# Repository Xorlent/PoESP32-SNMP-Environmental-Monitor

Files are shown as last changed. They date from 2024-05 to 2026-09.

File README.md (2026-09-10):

# The $32 SNMP Environmental Monitor
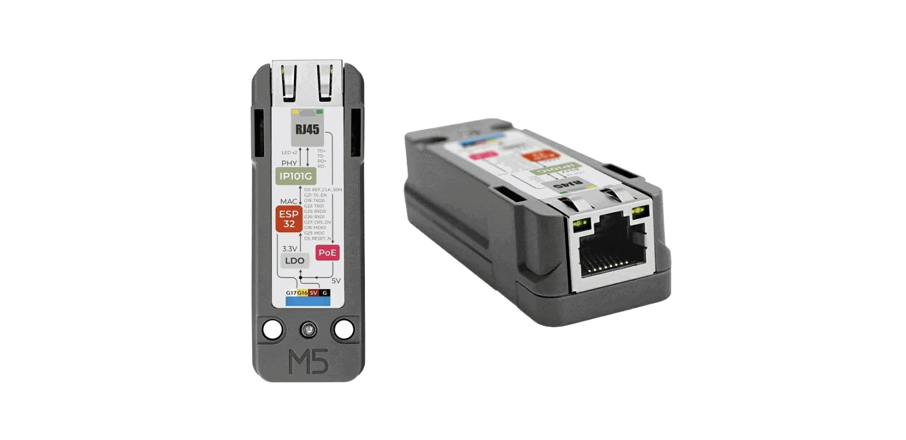
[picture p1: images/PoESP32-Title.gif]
PoESP32 Animated Image

## Background
With Vertiv unceremoniously stop-shipping and then discontinuing the [Geist Watchdog 15](https://www.vertiv.com/en-us/products-catalog/monitoring-control-and-management/monitoring/watchdog-15/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) during our deployment, we had to scramble to find a suitable equivalent device.  We were shocked to find a lack of decent options for small form-factor, PoE-powered devices that were not astronomically priced.  With M5Stack's PoE-powered ESP32 device in hand, we developed a network SNMP environmental monitor with a total all-in cost of less than 20% of competing products.

## Requirements
1. M5Stack [PoESP32 device](https://shop.m5stack.com/products/esp32-ethernet-unit-with-poe), or a newer [Unit-PoE-P4](https://shop.m5stack.com/products/unit-poe-with-esp32-p4), both around $25 USD
   - Notes on the Unit-PoE-P4:
     - Using the Unit-PoE-P4 significantly reduces the device operating specification from -17.7°C to 0°C and 60°C to 40°C
     - Requires NO disassembly or downloader kit, just a USB C cable for programming
     - The Unit-PoE-P4 device will not mount to any of the provided 3D-printable models.  I may produce revised designs for this if there is interest.
2. Sensor
   - M5Stack [ENV III sensor unit](https://shop.m5stack.com/products/env-iii-unit-with-temperature-humidity-air-pressure-sensor-sht30-qmp6988), currently $5.95 USD
   - or a custom SHT41-based sensor.  All files and instructions can be found in the /SHT4X folder.  As little as $2.20/each shipped in quantities of 30.
3. A single [M5Stack ESP32 Downloader kit](https://shop.m5stack.com/products/esp32-downloader-kit) (not required for Unit-PoE-P4), currently $9.95 USD

## Cost Analysis
One-time cost for a USB-to-serial device (PoESP32 only): $9.95 plus tax and shipping  
Total cost per unit: $31.85 plus tax and shipping  
Programming time per unit: < 10 minutes  

## Device Cost Comparison (temperature/humidity only)
- $32: this PoESP32-based device
- $220 before stop-ship: Vertiv Watchdog 15P (discontinued)
- $190 on sale: AKCP sensorProbe1+ Pro
- $315: NTI E-MICRO-TRHP
- $199: MONNIT PoE-X Temperature
- $295: Room Alert 3S

## Device Capability Comparison
This project produces a SNMPv1/2c temperature and humidity monitoring device with flashed configuration settings and no remote management capability.  Some would see this as a positive from a security-perspective, but it could prove challenging in network environments where change is constant.  A re-flash/re-programming is required to modify any configuration options:
- Host name
- Device IP and subnet
- IP gateway
- SNMP read community string
- Authorized SNMP monitoring node IP address list

__Bottom line: If you need SNMPv3 or desire web management and/or SNMP write functionality, you could enhance this project's code or simply purchase a commercial product.__  
_Update: See the [DHCP-Support Branch](https://github.com/Xorlent/PoESP32-SNMP-Environmental-Monitor/tree/DHCP-Support) to test the V.2.0 candidate with full DHCP configuration capabilities_

## Programming
_Once you've successfully programmed a single unit, skip step 1.  Repeating this process takes less than 5 minutes from start to finish._
1. [Set up your Arduino programming environment](https://github.com/Xorlent/PoESP32-SNMP-Environmental-Monitor/blob/main/ARDUINO-SETUP.md)
2. Disassemble the PoESP32 case (skip if using Unit-PoE-P4)
   - You will need a 1.5mm (M2) allen wrench to remove a single screw [pic](https://github.com/Xorlent/PoESP32-SNMP-Environmental-Monitor/blob/main/images/1-Allen.jpg)
   - Inserting a small flat head screwdriver into the slots flanking the Ethernet jack [pic](https://github.com/Xorlent/PoESP32-SNMP-Environmental-Monitor/blob/main/images/2-Slots.jpg), carefully separate the case halves; work it side by side to avoid damage [pic](https://github.com/Xorlent/PoESP32-SNMP-Environmental-Monitor/blob/main/images/3-Tabs.jpg)
> [!TIP]
> If you have fingernails, it can be quicker to slide a nail between the case halves, starting with the end opposite the Ethernet port and using another nail to pull the retaining tabs back
3. In Arduino, open the project file (PoESP32-SNMP-Environmental-Monitor.ino)
   - Edit the hostname, IP address, subnet, gateway, SNMP read community, and authorized hosts lists at the very top of the file.
   - Select Tools->Board->esp32 and select "ESP32 Dev Module" if using PoESP32
   - OR select Tools->Board->esp32 and select "ESP32P4 Dev Module" if using Unit-PoE-P4
     - Set ESP32P4 board parameters according to [this screenshot](https://github.com/Xorlent/PoESP32-SNMP-Environmental-Monitor/blob/main/images/ESP32P4-Config.jpg)
4. With the USB-to-serial adapter unplugged, insert the pins in the correct orientation on the back of the PoESP32 mainboard [pic](https://github.com/Xorlent/PoESP32-SNMP-Environmental-Monitor/blob/main/images/4-Programmer.jpg) (skip if using Unit-PoE-P4)
> [!WARNING]
> Do not plug the device into a powered Ethernet port until after step 7 or you risk damaging your USB port!
5. With light tension applied to ensure good connectivity to the programming through-hole vias on the PoESP32 (see step 4 pic), plug in the USB-to-serial adapter
   - The device is now in bootloader mode
   - For the Unit-PoE-P4, simply plug the USB cable into the USB port above the Ethernet jack
6. In Arduino
   - Select Tools->Port and select the USB-to-serial interface
     - If you're unsure, unplug the USB cable, look at the port list, then plug it back in and select the new entry (repeating step 5)
   - Select Sketch->Upload to flash the device
   - When you see something similar to the following, proceed to step 7.  If you see an error, try lowering the upload speed in the Tools menu.
     ```
     Writing at 0x000d0502... (100 %)
     Wrote 790896 bytes (509986 compressed) at 0x00010000 in 8.9 seconds (effective 714.8 kbit/s)...
     Hash of data verified.

     Leaving...
     Hard resetting via RTS pin...
7. Disconnect the USB cable and reassemble the case if applicable
8. Plug in the sensor accessory [pic](https://github.com/Xorlent/PoESP32-SNMP-Environmental-Monitor/blob/main/images/5-Assembled.jpg)
9. Connect the device to a PoE network port and mount as appropriate
   - The holes in the PoESP32 and ENV IV sensor cases work great with zip ties for rack install or screws if attaching to a backboard
     - See the /3Dmodels folder for print-able mounting plates or [Guidance and Limitations](https://github.com/Xorlent/PoESP32-SNMP-Environmental-Monitor/blob/main/README.md#guidance-and-limitations) for more detail
   - Do not mount the ENV IV directly on top of the PoESP32, as it generates enough heat to affect sensor readings
10. Configure your monitoring platform as appropriate
    - A list of valid OIDs this sensor will respond to can be found [here](https://github.com/Xorlent/PoESP32-SNMP-Environmental-Monitor/blob/main/OIDINFO.md)
    - Paessler (PRTG) produce a great freely-downloadable SNMP tester for Windows, available [here](https://www.paessler.com/tools/snmptester)
    - If you have PRTG, pre-configured device templates are available for this project at https://github.com/Xorlent/PRTG-OIDLIBS
    - Don't have a monitoring platform?  [PRTG Freeware](https://www.paessler.com/free_network_monitor) would support monitoring and alerting for up to 20 of these devices

## Guidance and Limitations
- For monitoring, configure one OID per sensor.  This custom SNMP parser will only respond to one OID per request.
- If you receive a "General Failure" when requesting a valid measurement OID, this means the device is having trouble communicating with the temperature/humidity sensor.
- If you request an invalid OID, expect no response.  The device will not process packets for requests that are not authorized or not a match for a valid OID.
- For high humidity environments, this device will activate an internal sensor heater under certain conditions to ensure more accurate readings.
- The device will respond to pings from any IP address within the routable network.
- Don't have PoE ports on your network switch?  No problem: https://www.amazon.com/gp/product/B0C239DGJF
- Need a simple solution for mounting the PoESP32 and environmental monitor as a unitized assembly?  Within the /3Dmodels folder you will find:
  1. PoESP32-Environmental-1RU-Base.step : 3D print model to mount the PoESP32 assembly into a 1U rack space (w/optional wire cover and LED lightguides)
  2. PoESP32-Environmental-Mini.step : 3D print model for zip tie mounting (space constrained)
  3. PoESP32-Environmental-Mini-Magnet.step : 3D print model for magnet mounting (space constrained, compatible with 8mm x 2mm disc magnets)
  4. PoESP32-Environmental-Mid.step : 3D print model for zip tie mounting
  5. PoESP32-Environmental-Mid-Magnet.step : 3D print model for magnet mounting (compatible with 8mm x 2mm disc magnets)
  6. If you want to modify the models and make your own custom design:
     - [Onshape link - 1RU Base](https://cad.onshape.com/documents/126ed9d0ea20223ee2558e2e/w/5dc774b929e3cc882e2ccc02/e/70eb0dc678e6fe37b06c7b4d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)
     - [Onshape link - 1RU Lightguides for single-material printing](https://cad.onshape.com/documents/126ed9d0ea20223ee2558e2e/w/5dc774b929e3cc882e2ccc02/e/16542899019e9250b0249f1e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)
     - [Onshape link - 1RU Wire Cover](https://cad.onshape.com/documents/126ed9d0ea20223ee2558e2e/w/5dc774b929e3cc882e2ccc02/e/cc43e711478951692c63e341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)
     - [Onshape link - Mini](https://cad.onshape.com/documents/126ed9d0ea20223ee2558e2e/w/f747afb8fc8c6e8e288e0fc9/e/70eb0dc678e6fe37b06c7b4d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)
     - [Onshape link - Mini Magnetic](https://cad.onshape.com/documents/126ed9d0ea20223ee2558e2e/w/bfca9ecb4e85ab436c8e3736/e/70eb0dc678e6fe37b06c7b4d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)
     - [Onshape link - Mid](https://cad.onshape.com/documents/126ed9d0ea20223ee2558e2e/w/86908f6e4038f162632614a8/e/70eb0dc678e6fe37b06c7b4d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)
     - [Onshape link - Mid Magnetic](https://cad.onshape.com/documents/126ed9d0ea20223ee2558e2e/w/887531df77e994a6e9e16eac/e/70eb0dc678e6fe37b06c7b4d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)

## Technical Information
- Operating Specifications
  - Operating temperature: 0°F (-17.7°C) to 140°F (60°C)
  - Operating humidity: 5% to 90% (RH), non-condensing
- Sensor Accuracy
  - ±0.2 °C，±1.8 %RH
- Power Consumption
  - 6W maximum via 802.3af Power-over-Ethernet
- Ethernet
  - IP101G PHY
  - 10/100 Mbit twisted pair copper
  - IEEE 802.3af Power-over-Ethernet
- I/O Configuration
  - SHT40 (ENV IV) or SHT30 (ENV III) temperature and humidity sensor
  - See [PORTINFO.md](https://github.com/Xorlent/PoESP32-SNMP-Environmental-Monitor/blob/main/PORTINFO.md)

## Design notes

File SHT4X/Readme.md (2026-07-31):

## This folder contains a temperature and humidity sensor that can be used in place of the now end-of-life M5Stack ENV-IV
1. A full PCB design that can be produced by JLCPCB for as little as $2.20 each (shipped) in quantities of 30
   - Upload the SHT41A.zip file to JLCPCB accepting all defaults
   - Select economic assembly service, top side only
   - Click "Next"
   - Upload SHT41A-BOM.csv for the "Bill of Materials" list
   - Upload SHT41A-all-pos.csv for the Pick & Place file
   - Click "Process BOM & CPL"
   - Ensure components match the BOM file (you can open this file in a text editor to verify results)  
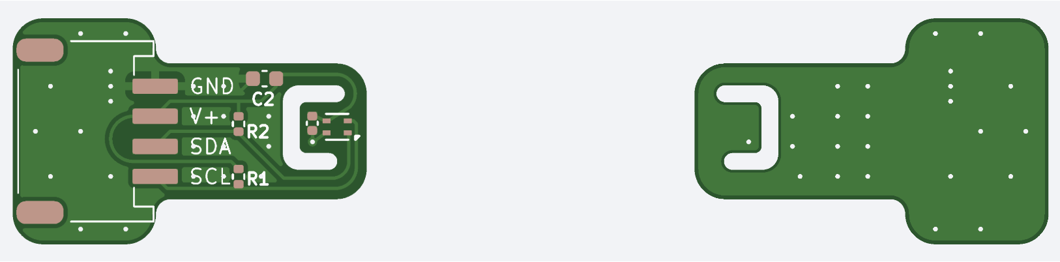
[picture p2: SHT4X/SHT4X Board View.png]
SHT4X Board View

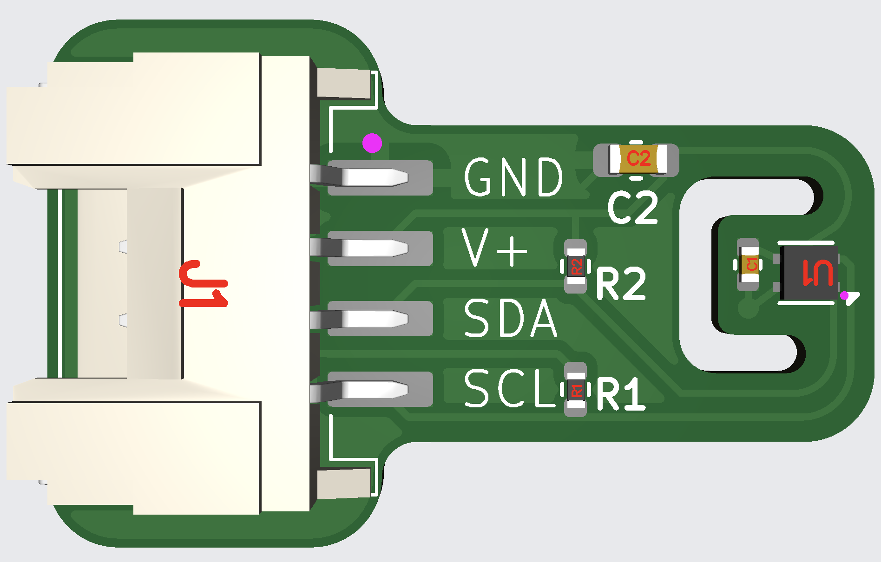
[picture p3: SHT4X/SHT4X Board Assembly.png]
SHT4X Board Assembly


2. A 3D-printable M5Stack sensor module compatible case
   - Print in PETG using a .4mm nozzle, .25mm layer height, .45mm extrusion width, 15% gyroid infill
   - Insert the assembled PC Board into the Bottom Shell
   - Using Weld-On #4 Cement, apply a small amount to the Top Shell barrels and the slots next to the connector opening
   - Assemble the shell halves, holding the top and bottom shells together for a few minutes

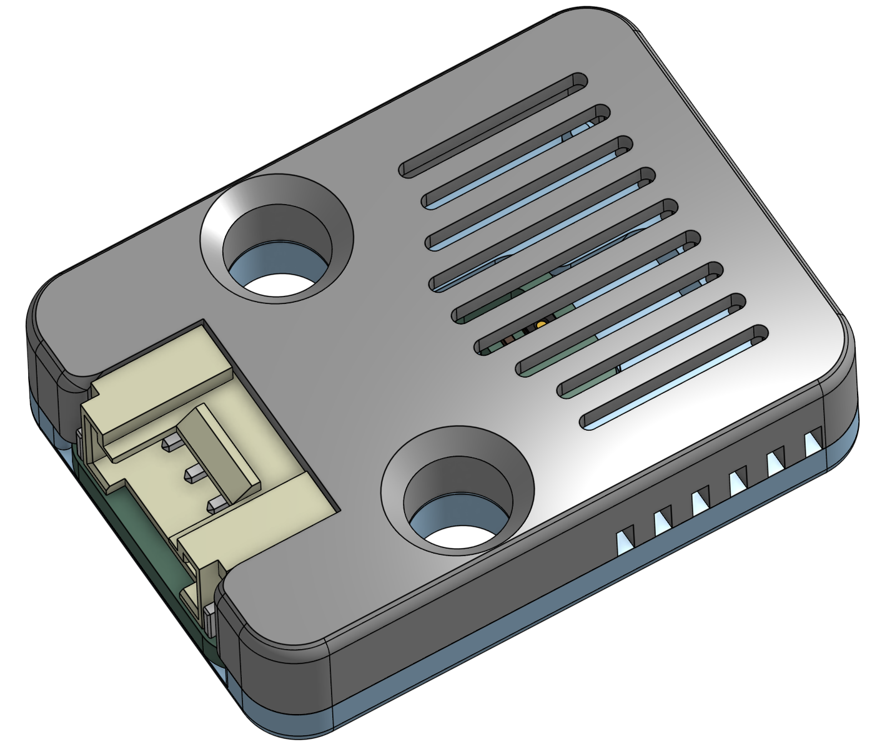
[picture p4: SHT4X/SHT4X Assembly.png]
SHT4X Sensor Module


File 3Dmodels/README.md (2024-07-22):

## This folder contains 3D print models for various device mounting options.
> [!NOTE]
> Take care to print these models in an appropriate material for the installation conditions (e.g. expected temperature and humidity)  
> For indoor, conditioned spaces, PETG is a great choice.  For high temperature environments, polycarbonate (PC) is recommended.
### PoESP32-SNMP-Environmental-1RU-Base, PoESP32-SNMP-Environmental-1RU-Lightguides, and PoESP32-Environmental-1RU-Base-Toolless
  - LED Lightguide features can be printed clear to allow Ethernet indicators to be seen even when mounted facing the rear of a rack
  - 1RU-Toolless-Nut and 1RU-Toolless-Stud only work with the PoESP32-Environmental-1RU-Base-Toolless model
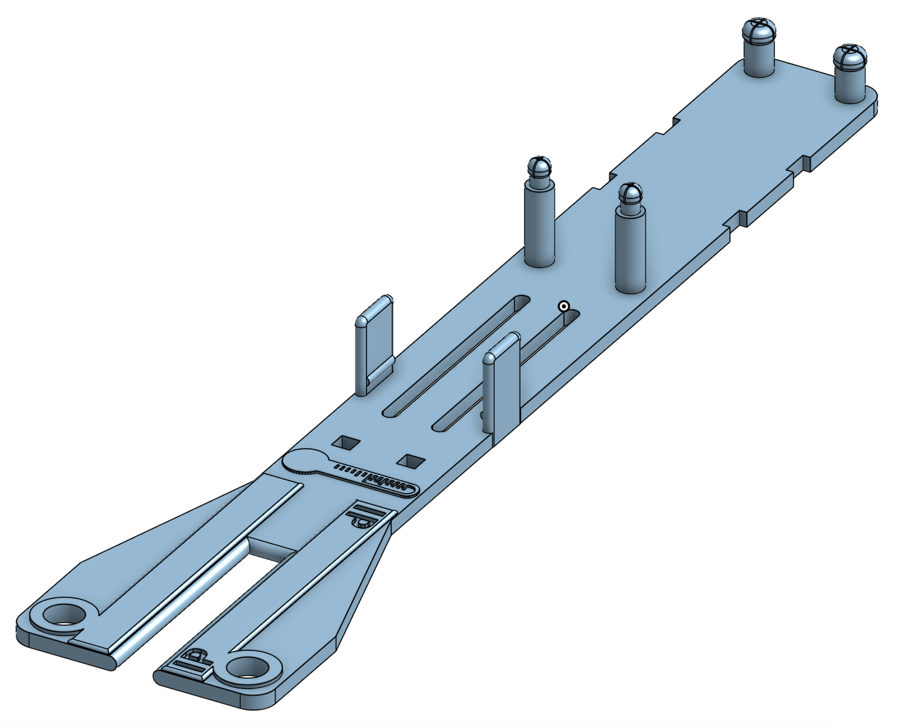
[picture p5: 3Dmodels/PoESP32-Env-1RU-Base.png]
PoESP32 1RU Model

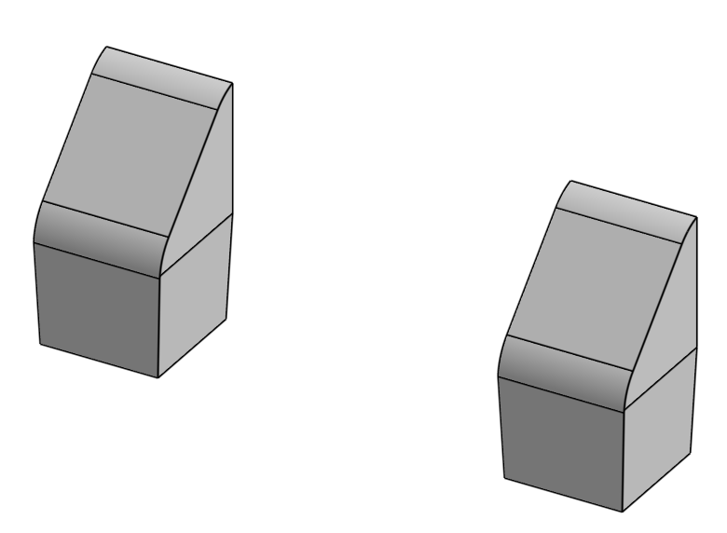
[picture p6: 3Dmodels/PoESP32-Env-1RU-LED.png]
PoESP32 1RU Model

### PoESP32-SNMP-Environmental-1RU-Cover
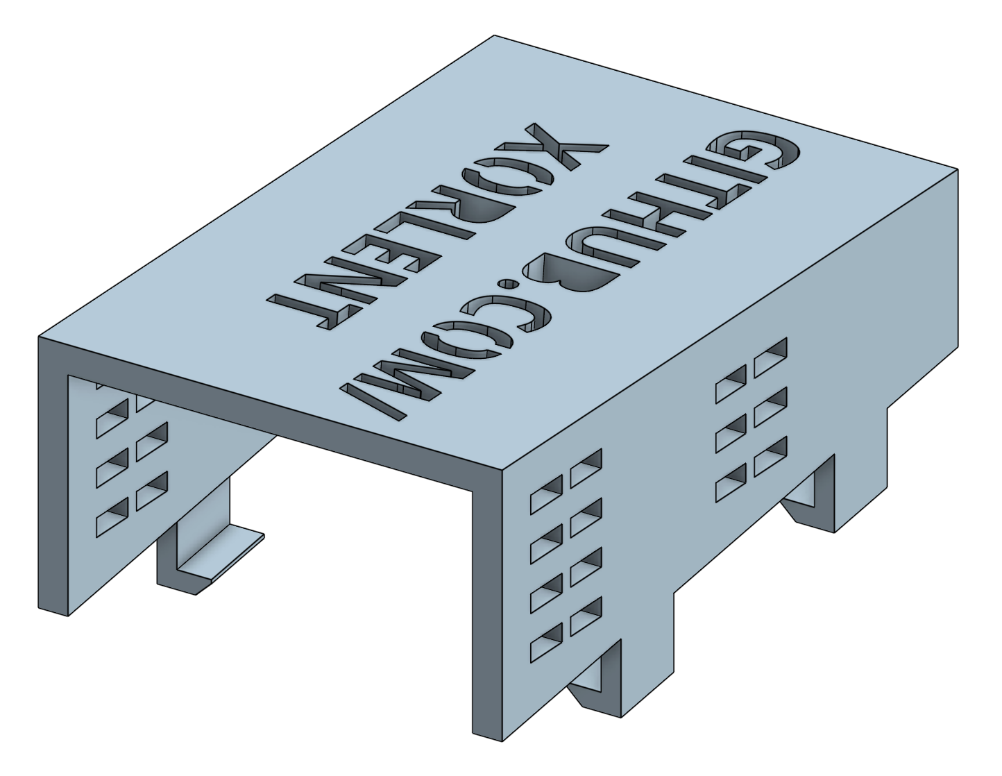
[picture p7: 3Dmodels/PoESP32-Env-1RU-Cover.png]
PoESP32 1RU Cover

### PoESP32-SNMP-Environmental-Mini
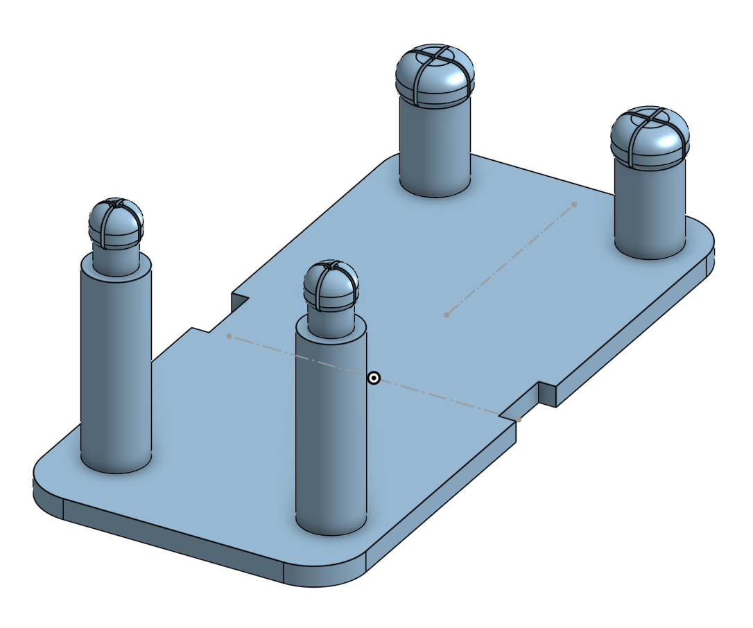
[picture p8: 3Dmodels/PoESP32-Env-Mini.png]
PoESP32 Mini Model

### PoESP32-SNMP-Environmental-Mini-Magnetic
_Compatible with 8mm x 2mm neodymium disc magnets_
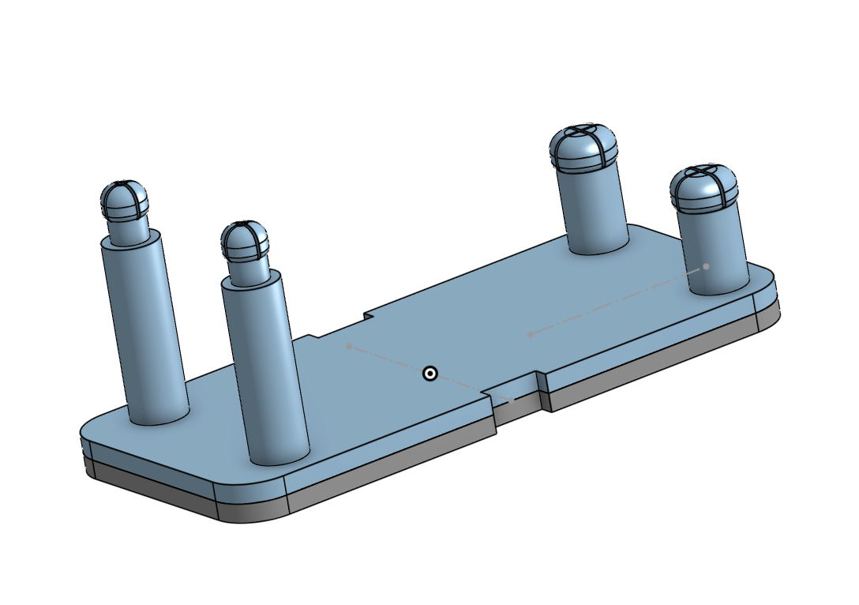
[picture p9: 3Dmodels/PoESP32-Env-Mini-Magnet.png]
PoESP32 Mini Magnetic Model

### PoESP32-SNMP-Environmental-Mini-Magnetic Internal View
_Compatible with 8mm x 2mm neodymium disc magnets_
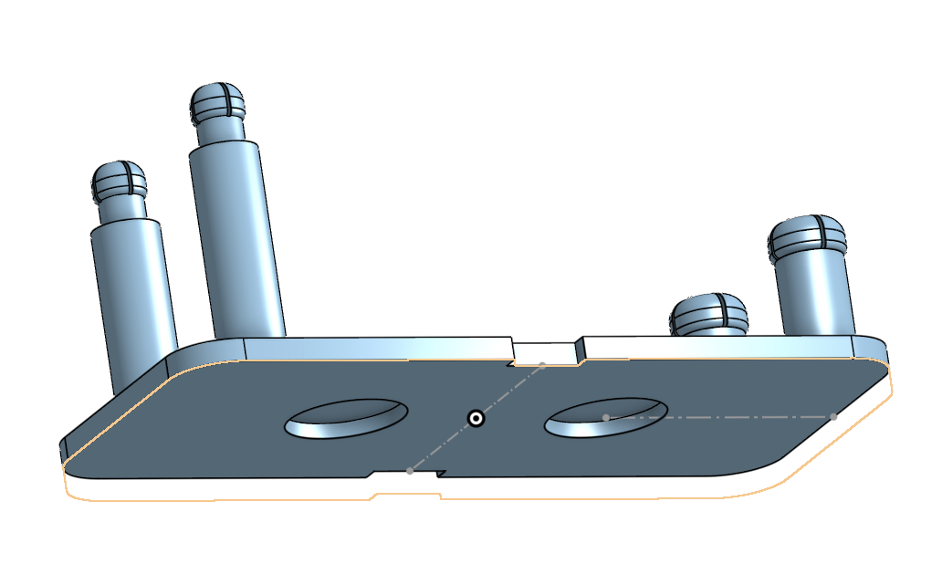
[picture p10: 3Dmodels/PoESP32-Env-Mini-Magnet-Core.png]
PoESP32 Mini Magnetic Internal View

### PoESP32-SNMP-Environmental-Mid
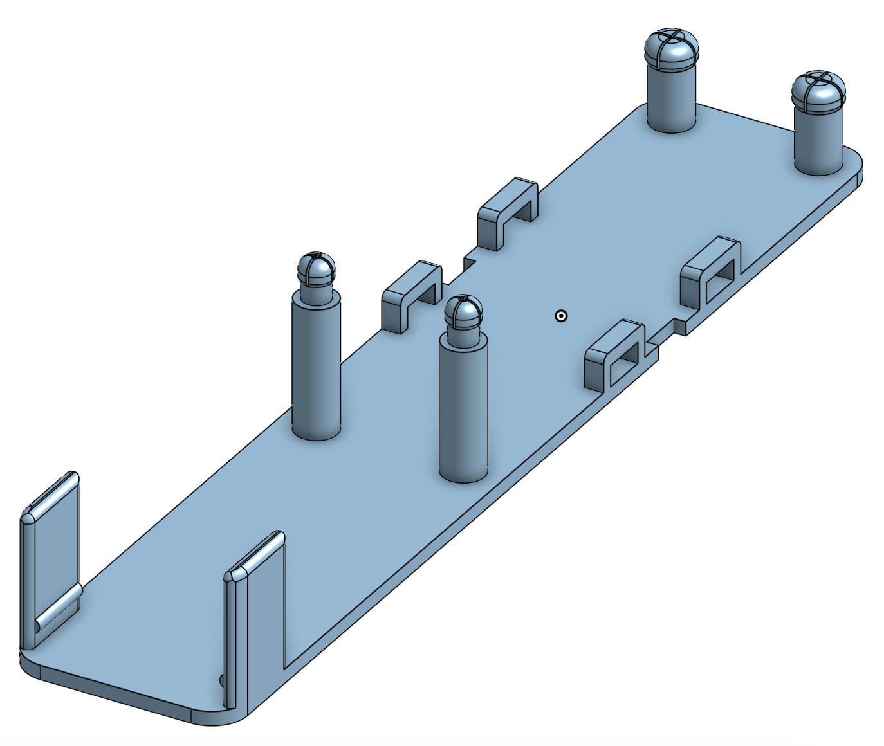
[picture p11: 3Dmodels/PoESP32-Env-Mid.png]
PoESP32 Mini Model

### PoESP32-SNMP-Environmental-Mid-Magnetic
_Compatible with 8mm x 2mm neodymium disc magnets_
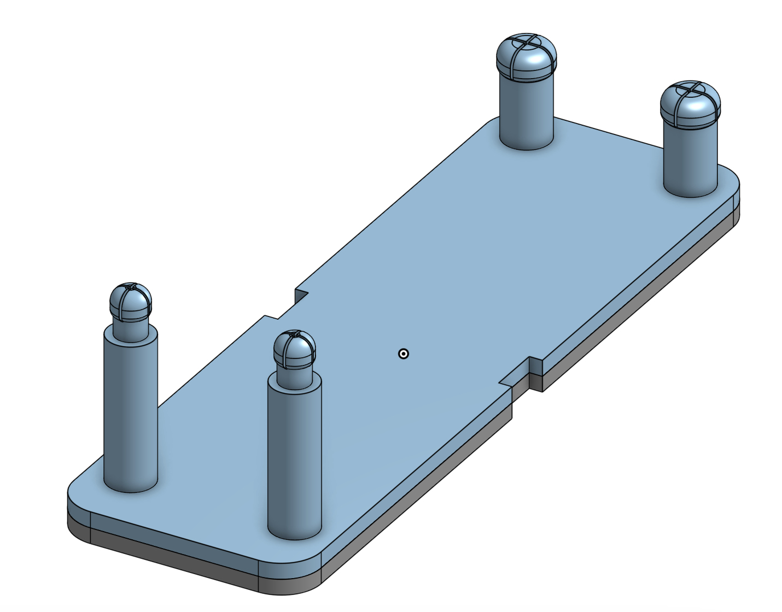
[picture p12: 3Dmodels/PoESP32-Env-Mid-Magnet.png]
PoESP32 Mini Magnetic Model


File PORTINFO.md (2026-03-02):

# M5Stack PoESP32 Port and Address Info
## GPIO
### Ethernet IP101G (SMI)
- MDC 23  
- MDIO 18  
- CLK 0  
- PWR 5  
- PHY ADDR 1  
### Ethernet IP101G (RMII)
- TX_EN 21  
- TX0 19  
- TX1 22  
- RX0 25  
- RX1 26  
- CRS_DV 27  
### I2C
- RX 16  
- TX 17  
## I2C DEVICES
### SHT40 Temp + Humidity
- Address 0x44

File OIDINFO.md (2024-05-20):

### Uptime
1.3.6.1.2.1.1.3.0
### Hostname
1.3.6.1.4.1.119.2.1.3.0
### Temperature (.1 degrees C)
1.3.6.1.4.1.119.5.1.2.1.5.1
### Temperature (degrees F)
1.3.6.1.4.1.119.5.1.2.1.5.2
### Humidity (%)
1.3.6.1.4.1.119.5.1.2.1.6.1

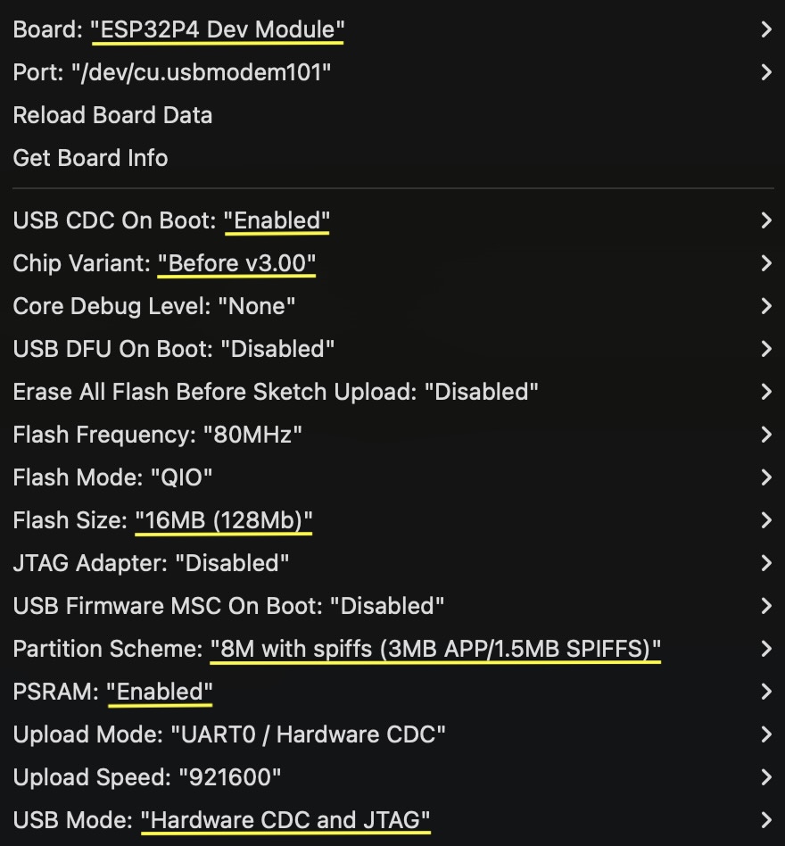
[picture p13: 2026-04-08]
images/ESP32P4-Config.jpg

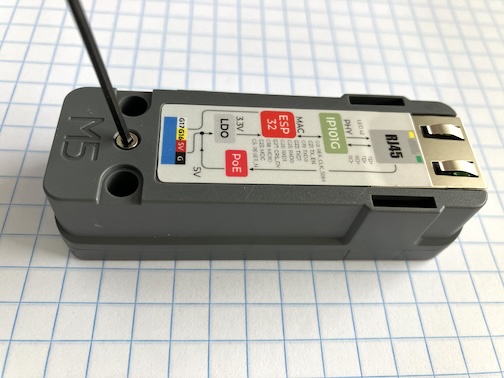
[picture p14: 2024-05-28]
images/1-Allen.jpg

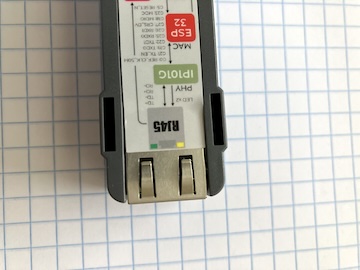
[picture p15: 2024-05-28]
images/2-Slots.jpg

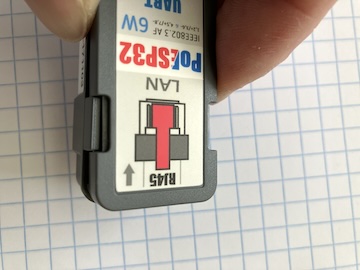
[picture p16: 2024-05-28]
images/3-Tabs.jpg

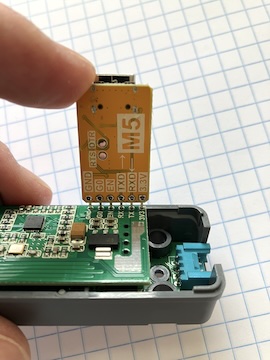
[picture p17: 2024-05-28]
images/4-Programmer.jpg

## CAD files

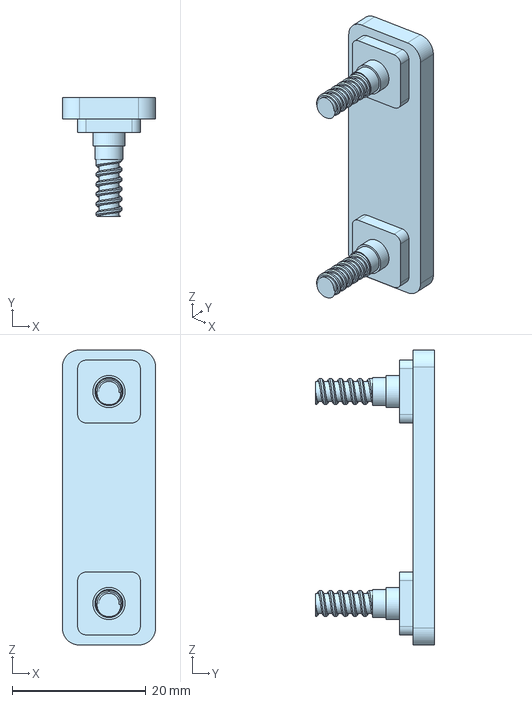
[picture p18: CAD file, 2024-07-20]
3Dmodels/PoESP32-Environmental-1RU-Toolless-Stud.step
14.0 x 17.8 x 44.2 mm

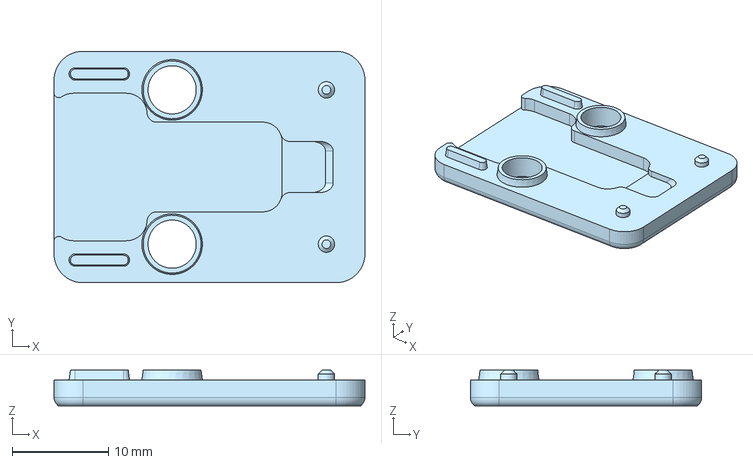
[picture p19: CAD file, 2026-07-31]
SHT4X/Bottom Shell - LCSC Connector.step
32.2 x 24.0 x 3.70 mm

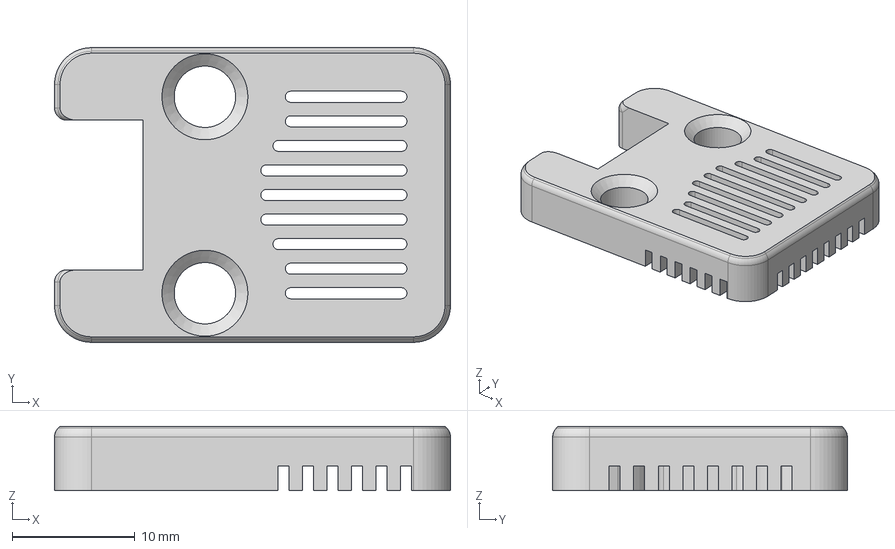
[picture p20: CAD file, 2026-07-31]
SHT4X/Top Shell - LCSC Connector.step
32.2 x 24.0 x 5.25 mm

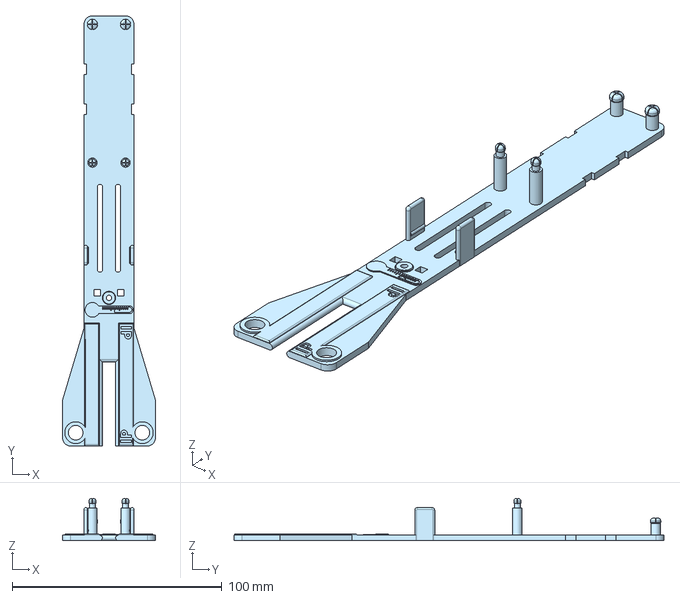
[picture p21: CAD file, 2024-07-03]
3Dmodels/PoESP32-Environmental-1RU-Base-Toolless.step
44.2 x 204.9 x 20.1 mm

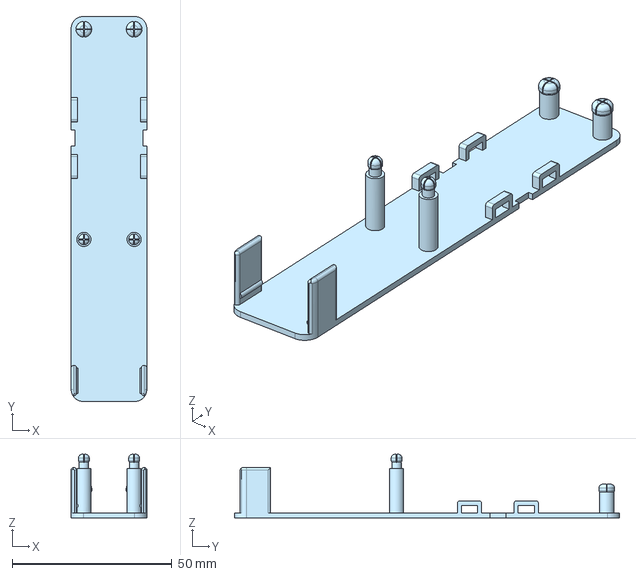
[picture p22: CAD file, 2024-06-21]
3Dmodels/PoESP32-Environmental-Mid.step
23.7 x 120.7 x 20.0 mm

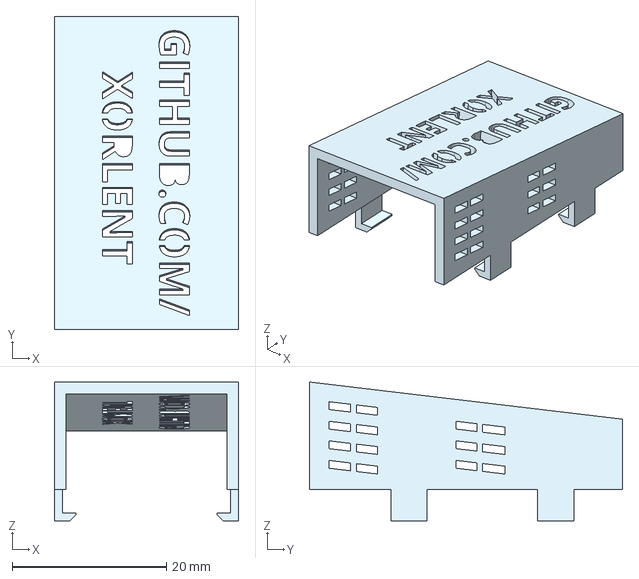
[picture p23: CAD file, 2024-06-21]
3Dmodels/PoESP32-Environmental-1RU-Cover.step
23.9 x 40.6 x 18.0 mm

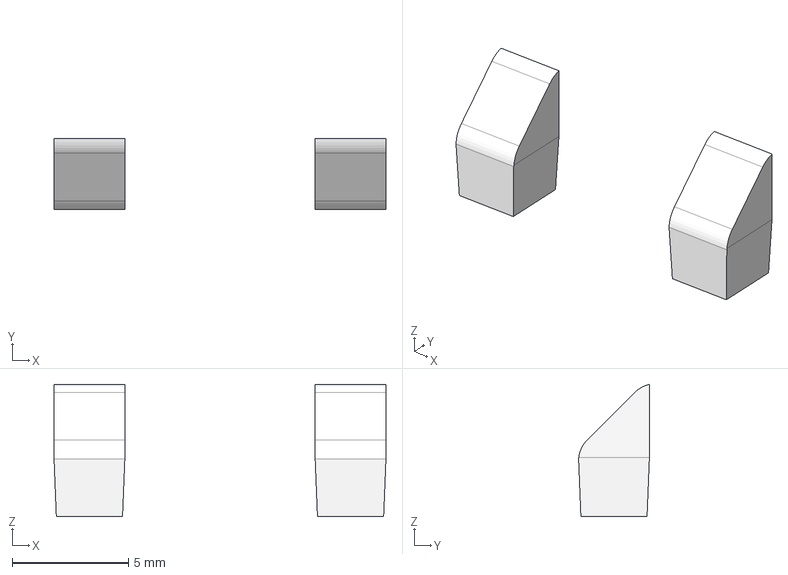
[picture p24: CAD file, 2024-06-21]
3Dmodels/PoESP32-Environmental-1RU-Lightguides.step
14.3 x 3.05 x 5.69 mm
LEDLightguideL
LEDLightguideR

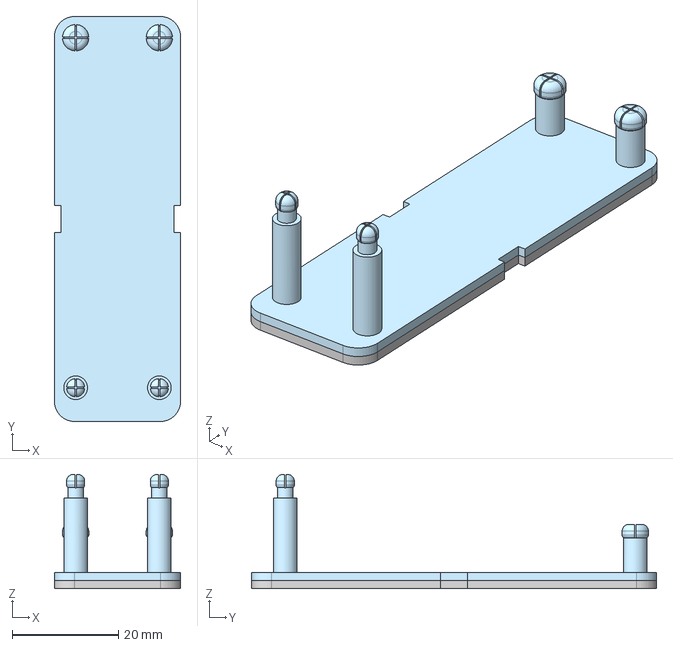
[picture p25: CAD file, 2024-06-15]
3Dmodels/PoESP32-Environmental-Mid-Magnet.step
23.7 x 76.2 x 21.5 mm
BasePlateBottom
BasePlateTop

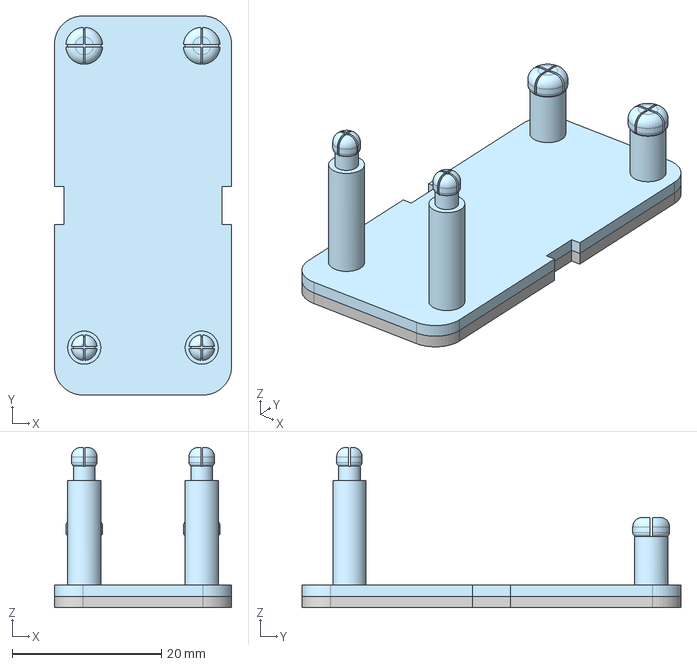
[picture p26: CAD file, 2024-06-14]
3Dmodels/PoESP32-Environmental-Mini-Magnet.step
23.7 x 50.8 x 21.5 mm
BasePlateBottom
BasePlateTop

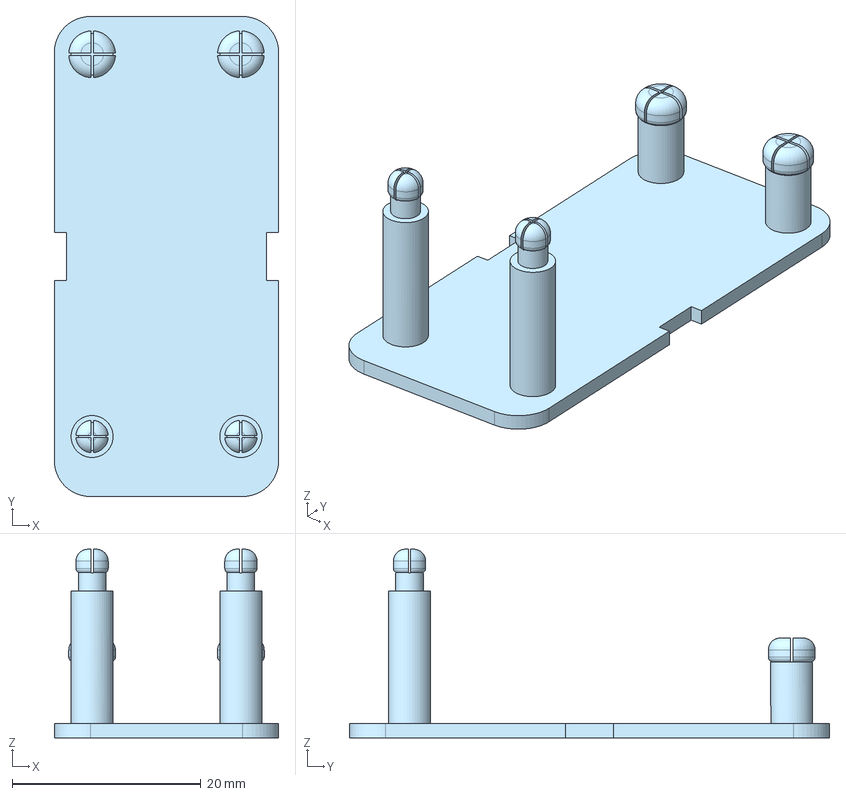
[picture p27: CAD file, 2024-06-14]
3Dmodels/PoESP32-Environmental-Mini.step
23.7 x 50.8 x 20.0 mm

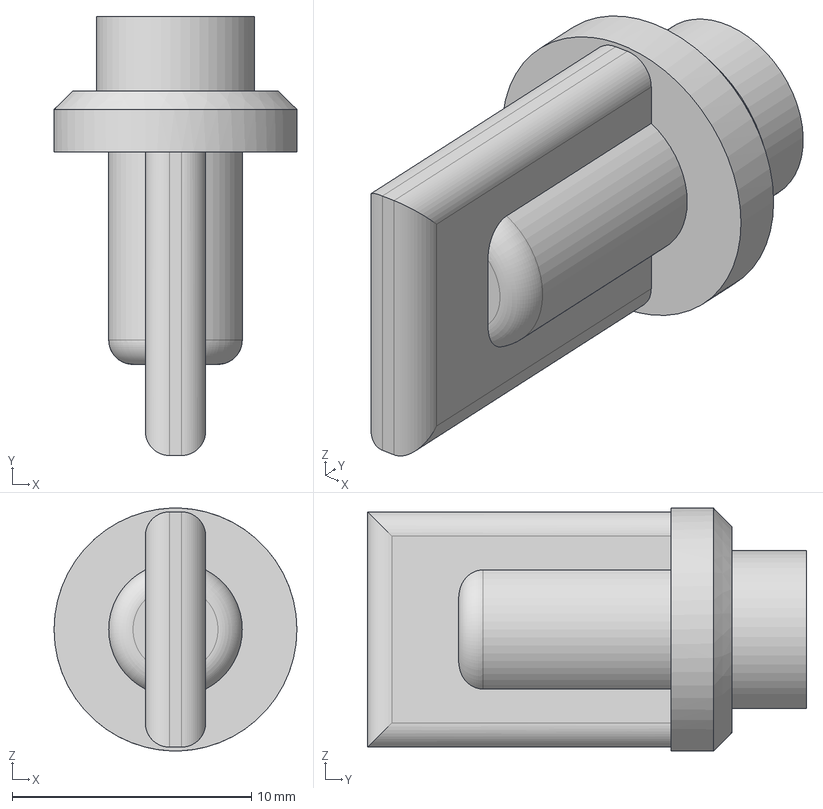
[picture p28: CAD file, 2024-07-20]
3Dmodels/PoESP32-Environmental-1RU-Toolless-Nut.step
10.2 x 18.4 x 10.2 mm

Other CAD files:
3Dmodels/PoESP32-Environmental-1RU-Base.step

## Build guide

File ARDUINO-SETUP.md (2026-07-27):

1. Download the latest Arduino IDE appropriate for your operating system (https://www.arduino.cc/en/software)
2. Open the Arduino IDE
3. Click File->Preferences or Arduino IDE->Settings (MacOS)
4. Open the Boards Manager
   - Type "esp32" in the search field and select "esp32 by Espressif Systems" (__NOT "Arduino ESP32 Boards"__)
     - Install version 3.3.X
5. Open the Libraries Manager
   - Type "sht4x" in the search field and select "SHT4x by Rob Tillaart"
     - Install version 0.1.2
   - Type "arduino-timer" in the search field and select "arduino-timer by Michael Contreras"
     - Install version 3.0.1
6. For PoESP32 only: Install the CH9102 USB-to-serial drivers ([Windows](https://learn.adafruit.com/how-to-install-drivers-for-wch-usb-to-serial-chips-ch9102f-ch9102/windows-driver-installation)/[MacOS](https://learn.adafruit.com/how-to-install-drivers-for-wch-usb-to-serial-chips-ch9102f-ch9102/mac-driver-installation))
   - There is no need to run setup.exe in Windows -- simply right-click the driver .inf file in the Win1X directory and select "Install"

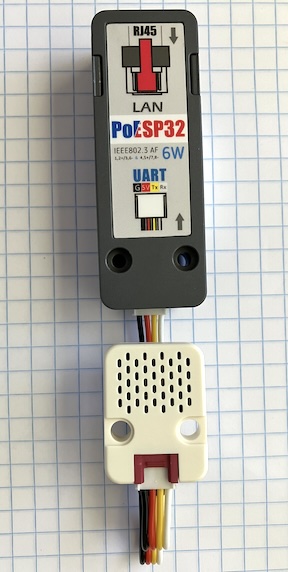
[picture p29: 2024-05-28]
images/5-Assembled.jpg

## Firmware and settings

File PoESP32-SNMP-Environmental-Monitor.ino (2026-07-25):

/*
GNU GENERAL PUBLIC LICENSE Version 3, 29 June 2007
https://github.com/Xorlent/PoESP32-SNMP-Environmental-Monitor

Libraries and supporting code incorporates other licenses, see https://github.com/Xorlent/PoESP32-SNMP-Environmental-Monitor/blob/main/LICENSE-3RD-PARTY.md
*/
////////------------------------------------------- CONFIGURATION SETTINGS AREA --------------------------------------------////////

const char HOSTNAME[] = "PoESP32-Unit"; // Set hostname

// Ethernet configuration
IPAddress ip(192, 168, 1, 99); // Set device IP address.
IPAddress gateway(192, 168, 1, 1); // Set default gateway IP address.
IPAddress subnet(255, 255, 255, 0); // Set network subnet mask.

// SNMP read community configuration
const char SNMP_READCOMMUNITY_VALUE_7[] = "readonly"; // Set SNMP read community for your environment.

//The AUTHORIZED_HOSTS list should include the IP of any hosts that may query this device via SNMP.
const IPAddress AUTHORIZED_HOSTS[] = {IPAddress(192,168,1,1),IPAddress(192,168,1,10)};

/* Valid OIDs (Must query one OID per request):
### Uptime
1.3.6.1.2.1.1.3.0
### Hostname
1.3.6.1.4.1.119.2.1.3.0
### Temperature (.1 degrees C)
1.3.6.1.4.1.119.5.1.2.1.5.1
### Temperature (degrees F)
1.3.6.1.4.1.119.5.1.2.1.5.2
### Humidity (%)
1.3.6.1.4.1.119.5.1.2.1.6.1
*/

////////--------------------------------------- DO NOT EDIT ANYTHING BELOW THIS LINE ---------------------------------------////////

#include <ETH.h>
#include <AsyncUDP.h>
#include <SHT4x.h>
#include <arduino-timer.h>

#define SHT4X_DEBUG               false   // true enables heated measurement / equilibrium debug serial output
#define EQUILIBRIUM_WINDOW_SIZE   8       // 8 samples = 2 seconds @ 250ms intervals
#define DEFAULT_EQUILIBRIUM_TIMEOUT 60000 // ms
#define DEFAULT_DT_THRESHOLD      0.034   // °C/s max rate of change to declare equilibrium (adjusted from 0.030 used with the now end-of-life ENV IV module)

// Board-specific configuration
#define ETH_ADDR        1

#if defined(CONFIG_IDF_TARGET_ESP32P4)
// ESP32-P4 (Unit-PoE-P4) configuration
#define ETH_POWER_PIN   51
#define ETH_TYPE        ETH_PHY_TLK110
#define ETH_PHY_MDC     31
#define ETH_PHY_MDIO    52
#define ETH_CLK_MODE    EMAC_CLK_EXT_IN
#define I2C_SDA         53
#define I2C_SCL         54
#else
// ESP32 (default Unit-PoE) configuration
#define ETH_POWER_PIN   5
#define ETH_TYPE        ETH_PHY_IP101
#define ETH_PHY_MDC     23
#define ETH_PHY_MDIO    18
#define ETH_CLK_MODE    ETH_CLOCK_GPIO0_IN
#define I2C_SDA         16
#define I2C_SCL         17
#endif

////////---------------------------------------        Create runtime objects        ---------------------------------------////////

// Calculate the length of the user-specifed hostname string.
static const uint8_t HOSTNAME_LEN = sizeof(HOSTNAME)-1;

// Calculate the number of authorized hosts.
const unsigned int AUTHORIZED_HOSTS_QTY = sizeof(AUTHORIZED_HOSTS)/sizeof(IPAddress);

// Asynchronous UDP object
AsyncUDP udp;

// Byte strings for managing SNMP packet data:
static const uint8_t SNMP_ASN1_0[1] = {0x30};
static const uint8_t SNMP_VER1_2[3] = {0x02,0x01,0x00};
static const uint8_t SNMP_VER2_2[3] = {0x02,0x01,0x01};
static const uint8_t SNMP_READCOMMUNITY_5[1] = {0x04};
static const uint8_t SNMP_READCOMMUNITY_LEN_6[1] = {sizeof(SNMP_READCOMMUNITY_VALUE_7)-1};
static const uint8_t SNMP_GETREQUEST_7_LEN[1] = {0xa0};

uint8_t SNMP_GETREQUEST_DATA0[7] = {0x00,0x00,0x00,0x00,0x00,0x00,0x00}; // ASN.1, length (calc at runtime), ver int, ver len, ver value, community, community len
uint8_t SNMP_GETREQUEST_DATA1[2] = {0xa2,0x00}; // request_type (0xa2), length (calc at runtime)
uint8_t SNMP_GETREQUEST_DATA2a[8] = {0x00,0x00,0x00,0x00,0x00,0x00,0x00,0x00}; // Request ID int, RID length, RID ID[0], RID ID[1], RID ID[2], RID ID[3], RID ID[4], RID ID[5]
uint8_t SNMP_GETREQUEST_DATA2b[6] = {0x00,0x00,0x00,0x00,0x00,0x00}; // err int, err len, err value, index int, index len, index value
uint8_t SNMP_GETREQUEST_DATA3[6] = {0x00,0x00,0x00,0x00,0x00,0x00}; // Varbind list type, Varbind list len, Varbind type, Varbind len, Object ID, Object ID len

static const uint8_t SNMP_GETUPTIME[10] = {0x2b,0x06,0x01,0x02,0x01,0x01,0x03,0x00,0x05,0x00};
static const uint8_t SNMP_GETHOST[12] = {0x2b,0x06,0x01,0x04,0x01,0x77,0x02,0x01,0x03,0x00,0x05,0x00};
static const uint8_t SNMP_GETTEMPC[14] = {0x2b,0x06,0x01,0x04,0x01,0x77,0x05,0x01,0x02,0x01,0x05,0x01,0x05,0x00};
static const uint8_t SNMP_GETTEMPF[14] = {0x2b,0x06,0x01,0x04,0x01,0x77,0x05,0x01,0x02,0x01,0x05,0x02,0x05,0x00};
static const uint8_t SNMP_GETHUMIDITY[14] = {0x2b,0x06,0x01,0x04,0x01,0x77,0x05,0x01,0x02,0x01,0x06,0x01,0x05,0x00};

// Blocking flag to avoid packet processing contention in case we're flooded with requests
volatile bool blocking = false;

// Sampling result flag to indicate a problem with the SHT40 sensor
volatile bool sampleError = false;

// I2C SHT4x sensor object (RobTillaart library)
SHT4x sht;

// Forward declarations for functions in SHT4x_advancedFunctions.ino
bool requestAuto(measType initialMeasurement = SHT4x_MEASUREMENT_MEDIUM,
                 uint16_t timeout = DEFAULT_EQUILIBRIUM_TIMEOUT,
                 float threshold = DEFAULT_DT_THRESHOLD);
bool autoReady();
float getAutoTemperature();
float getAutoHumidity();
extern bool needsHeating;

// Periodic temp & humidity sampling timer
auto timer = timer_create_default();

// Flag: a requestAuto() cycle is in flight
volatile bool measurementInProgress = false;

// Holds current sample values
volatile uint8_t pHumidity = 0;
volatile int16_t fTemp = 0;
volatile int16_t cTemp = 0;

////////---------------------------------------     End create runtime objects     ---------------------------------------////////

////////---------------------------------------       Function declarations        ---------------------------------------////////

// SHT4x sensor sampling function, used by the non-blocking timer and executed every 30 seconds
bool sample(void *);
// Celcius to farenheit conversion
int ctof(float x);
// Verifies authorized caller by checking request IP
bool authRequest(IPAddress callerIP);
// Parses incoming SNMP messages received from valid authorized IP addresses
int parseRequest(uint8_t *payload, size_t length);
// Constructs and sends the response message for valid OID getRequests
void sendGetResponse(int request, IPAddress caller, uint16_t port);

////////---------------------------------------     End function declarations      ---------------------------------------////////

bool sample(void *)
{
    if (measurementInProgress) return true; // Previous cycle still in progress, skip this tick

    if (!requestAuto())
    {
      Serial.println("Error starting auto measurement");
      sampleError = true;
      return true;
    }
    measurementInProgress = true;
    return true; // Leave timer enabled.
}

// Celcius to Farenheit conversion function
int ctof(float x)
{
  return (int)roundf(1.8f * x + 32.0f);
}

// Verify caller is authorized
bool authRequest(IPAddress callerIP)
{
  for(int i=0;i<AUTHORIZED_HOSTS_QTY;i++)
  {
    if (callerIP == AUTHORIZED_HOSTS[i])
    {
      return true;
    }
  }
  return false;
}

// Parse and validate GetRequest
// Returns -1 for invalid/unsupported, 0 for uptime, 1 for hostname, 2 for .1 degrees C, 3 for degrees F, 4 for humidity
int parseRequest(uint8_t *payload, size_t length)
{
  if (!payload) return -1; // Null request
  if(blocking == false)
  {
    blocking = true;
    if(memcmp(SNMP_ASN1_0,payload,sizeof(SNMP_ASN1_0)) == 0)
    {
      Serial.print("ASN1: Valid");
      Serial.println();
      if(memcmp(SNMP_VER1_2,payload+2,sizeof(SNMP_VER1_2)) == 0 || memcmp(SNMP_VER2_2,payload+2,sizeof(SNMP_VER2_2)) == 0)
      {
        Serial.print("SNMP Version 1 or 2: Valid");
        Serial.println();
        if(memcmp(SNMP_READCOMMUNITY_5,payload+5,sizeof(SNMP_READCOMMUNITY_5)) == 0)
        {
          Serial.print("Read Community Supplied");
          Serial.println();
          if(memcmp(SNMP_READCOMMUNITY_LEN_6,payload+6,sizeof(SNMP_READCOMMUNITY_LEN_6)) == 0)
          {
            Serial.print("Read Community Length Matched");
            Serial.println();
            if(memcmp(SNMP_READCOMMUNITY_VALUE_7,payload+7,sizeof(SNMP_READCOMMUNITY_VALUE_7)-1) == 0)
            {
              Serial.print("Read Community Value Matched");
              Serial.println();
              if(memcmp(SNMP_GETREQUEST_7_LEN,payload+6+sizeof(SNMP_READCOMMUNITY_VALUE_7),sizeof(SNMP_GETREQUEST_7_LEN)) == 0)
              {
                Serial.print("Processing GetRequest...");
                Serial.println();
                
                // Copy portions of the caller's request info into buffers for us to then send back in the response.
                memcpy(SNMP_GETREQUEST_DATA0,payload,7);
                uint8_t RIDLength = payload[9+sizeof(SNMP_READCOMMUNITY_VALUE_7)]; // Retrieve the Request ID value length
                if (RIDLength > 6) return -1; // Prevent overflow of SNMP_GETREQUEST_DATA2a[8] (RIDLength+2 must be <= 8)
                if (9+sizeof(SNMP_READCOMMUNITY_VALUE_7)-1+RIDLength+2+6+6 > length) return -1; // Prevent out-of-bounds memory read
                memcpy(SNMP_GETREQUEST_DATA2a,payload+9+sizeof(SNMP_READCOMMUNITY_VALUE_7)-1,RIDLength+2); // Get the Request ID info
                memcpy(SNMP_GETREQUEST_DATA2b,payload+9+sizeof(SNMP_READCOMMUNITY_VALUE_7)-1+RIDLength+2,6); // Get the Error info
                memcpy(SNMP_GETREQUEST_DATA3,payload+9+sizeof(SNMP_READCOMMUNITY_VALUE_7)-1+RIDLength+2+6,6); // Get Varbind and Object info

                // We finished processing a valid uptime request packet.  Return 0 to the caller.
                if(memcmp(SNMP_GETUPTIME,payload+length-sizeof(SNMP_GETUPTIME),sizeof(SNMP_GETUPTIME)) == 0)
                {
                  return 0;
                }
                // We finished processing a valid hostname request packet.  Return 1 to the caller.
                if(memcmp(SNMP_GETHOST,payload+length-sizeof(SNMP_GETHOST),sizeof(SNMP_GETHOST)) == 0)
                {
                  return 1;
                }
                // We finished processing a valid .1 degrees C request packet.  Return 2 to the caller.
                if(memcmp(SNMP_GETTEMPC,payload+length-sizeof(SNMP_GETTEMPC),sizeof(SNMP_GETTEMPC)) == 0)
                {
                  return 2;
                }
                // We finished processing a valid degrees F request packet.  Return 3 to the caller.
                if(memcmp(SNMP_GETTEMPF,payload+length-sizeof(SNMP_GETTEMPF),sizeof(SNMP_GETTEMPF)) == 0)
                {
                  return 3;
                }
                // We finished processing a valid % relative humidity request packet.  Return 4 to the caller.
                if(memcmp(SNMP_GETHUMIDITY,payload+length-sizeof(SNMP_GETHUMIDITY),sizeof(SNMP_GETHUMIDITY)) == 0)
                {
                  return 4;
                }
                // We don't know what this is, print to serial console for debugging
                Serial.println();
                Serial.print("Unsupported or invalid payload: ");
                for(int idx = 0; idx < length; idx++)
                {
                  Serial.printf("%02x",payload[idx]);
                }
                Serial.println();
                Serial.println();
                return -1; // Unsupported/unknown request
              }
              return -1; // Unsupported/unknown request
            }
            return -1; // Unsupported/unknown request
          }
          return -1; // Unsupported/unknown request
        }
        return -1; // Unsupported/unknown request
      }
      return -1; // Unsupported/unknown request
    }
    return -1; // Unsupported/unknown request
  }
  return -1; // Currently blocked processing a request.  We'll ignore this one, release the blocking flag, and wait for a subsequent request to come in.
}
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
void loop() {
  timer.tick(); // Temp & humidity sampling

  if (measurementInProgress && autoReady())
  {
    if (sht.getError() == SHT4x_OK)
    {
      float aTemperature = getAutoTemperature();
      float aHumidity = getAutoHumidity();
      fTemp = ctof(aTemperature);                          // Calculate degrees F
      cTemp = (int16_t)roundf(aTemperature * 10.0f);       // SNMP degrees C is an integer in .1 degrees C
      pHumidity = (uint8_t)roundf(aHumidity);

      Serial.print("Temp: ");
      Serial.print(cTemp);
      Serial.print("C, ");
      Serial.print(fTemp);
      Serial.print("F | Humidity: ");
      Serial.println(pHumidity);

      sampleError = false;
    }
    else
    {
      Serial.print("Sensor error: 0x");
      Serial.println(sht.getError(), HEX);
      sampleError = true;
    }
    measurementInProgress = false;
  }
}

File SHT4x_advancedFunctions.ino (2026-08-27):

//
//    FILE: SHT4x_advancedFunctions.ino
//  AUTHOR: Xorlent (https://github.com/Xorlent)
// PURPOSE: Auto mode functions for automatic heating and equilibrium detection
//     URL: https://github.com/RobTillaart/SHT4x
//
//  This file contains reusable functions that can be copied to your own project.
//  
//  Auto mode handles high-humidity conditions automatically:
//  - Measures initial conditions
//  - Applies intelligent heating if needed (based on temp/humidity)
//  - Waits for temperature equilibrium after heating
//  - Returns final temperature and humidity values
//
//  Usage:
//    1. Call requestAuto() to start measurement
//    2. Poll autoReady() until it returns true (at least every 50 ms)
//    3. Get results with getAutoTemperature() and getAutoHumidity()
//
//  Debug Output Control:
//    Define SHT4X_DEBUG as true in your sketch to enable debug serial output:
//      #define SHT4X_DEBUG true

//  Debug output macros
#if SHT4X_DEBUG
  #define DEBUG_PRINT(...) Serial.print(__VA_ARGS__)
  #define DEBUG_PRINTLN(...) Serial.println(__VA_ARGS__)
#else
  #define DEBUG_PRINT(...)
  #define DEBUG_PRINTLN(...)
#endif

enum AutoState {
  AUTO_IDLE,
  AUTO_WAITING_HEATED,
  AUTO_EQUILIBRIUM_CHECK,
  AUTO_COMPLETE
};

/////////////////////////////////////////////////////////////////
//
//  STATE VARIABLES
//

AutoState autoState = AUTO_IDLE;
uint32_t autoStartTime;
uint32_t lastEquilibriumSample;
uint16_t equilibriumTimeout;
float dTthreshold;
bool needsHeating;

measType equilibriumMeasurementType;
float temperatureWindow[EQUILIBRIUM_WINDOW_SIZE];
uint8_t windowIndex;
uint8_t windowCount;
float originalTemperature;
float originalHumidity;

/////////////////////////////////////////////////////////////////
//
//  FUNCTIONS
//

//  Starts an automatic measurement cycle
//  Returns: true if started successfully, false on error
bool requestAuto(measType initialMeasurement, 
                 uint16_t timeout, 
                 float threshold)
{
  equilibriumTimeout = timeout;
  dTthreshold = threshold;
  autoState = AUTO_IDLE;
  
  DEBUG_PRINTLN("\n=== Starting Auto Mode ===");
  autoStartTime = millis();

  //  Take initial blocking measurement to assess conditions
  if (!sht.read(initialMeasurement, true))
  {
    DEBUG_PRINTLN("ERROR: Failed to read initial measurement");
    return false;
  }
  
  originalTemperature = sht.getTemperature();
  originalHumidity = sht.getHumidity();

  //  Decide if heated mode is needed
  measType heatedMode;
  needsHeating = false;
  
  if (originalTemperature < 55.0f && originalHumidity >= 85.0f) 
  {
    heatedMode = SHT4x_MEASUREMENT_LONG_HIGH_HEAT;
    needsHeating = true;
    DEBUG_PRINTLN("High humidity detected: Using HIGH heat (200mW, 1s)");
  } 
  else if (originalTemperature >= 55.0f && originalTemperature < 65.0f && originalHumidity >= 85.0f) 
  {
    heatedMode = SHT4x_MEASUREMENT_LONG_MEDIUM_HEAT;
    needsHeating = true;
    DEBUG_PRINTLN("High humidity detected: Using MEDIUM heat (110mW, 1s)");
  } 
  else if (originalTemperature < 65.0f && originalHumidity > 79.0f && originalHumidity < 85.0f) 
  {
    heatedMode = SHT4x_MEASUREMENT_LONG_LOW_HEAT;
    needsHeating = true;
    DEBUG_PRINTLN("Elevated humidity detected: Using LOW heat (20mW, 1s)");
  }
  
  if (!needsHeating)
  {
    autoState = AUTO_COMPLETE;
    return true;
  }
  
  //  Request async heated measurement
  DEBUG_PRINTLN("Requesting heated measurement...");
  if (!sht.requestData(heatedMode))
  {
    DEBUG_PRINTLN("ERROR: Failed to request heated measurement");
    return false;
  }

  equilibriumMeasurementType = initialMeasurement;
  autoState = AUTO_WAITING_HEATED;
  return true;
}
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

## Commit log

2024-05-20 Update and rename ARDUINO-SETUP.MD to ARDUINO-SETUP.md
2024-05-23 millis() to esp_timer_get_time
    Avoids 49 day wrap-around for device uptime OID value
    [PoESP32-SNMP-Sensor.ino]
2024-05-25 Fixes uncaught parser exceptions
    [PoESP32-SNMP-Sensor.ino]
2024-05-27 Update PoESP32-SNMP-Sensor.ino
    Added Ethernet link initialization wait
2024-06-13 Add 3D printer models for mounting
    [PoESP32-Environmental-1RU.step, PoESP32-Environmental-Mini.step]
2024-06-16 Handle > 127 degrees F
    During torture testing, the device was still operating correctly at 128F. Update code to allow for up to 60C/140F measurement before returning SNMP getResponse error
    [PoESP32-SNMP-Sensor.ino]
2024-06-21 Fully cradles PoESP module
    [PoESP32-Environmental-Mid.step]
2024-07-20 Optional for 1RU rack mounting
    [PoESP32-Environmental-1RU-Toolless-Nut.step, PoESP32-Environmental-1RU-Toolless-Stud.step]
2025-03-28 Update PoESP32-SNMP-Sensor.ino
    Add null check in parseRequest()
2025-03-28 Update PoESP32-SNMP-Sensor.ino
    Add check to prevent out of bounds memory access in parseRequest
    [PoESP32-SNMP-Sensor.ino]
2025-03-28 Update PoESP32-SNMP-Sensor.ino
    Automatically calculate the number of authorized hosts to simplify setup
2025-03-28 Update PoESP32-SNMP-Sensor.ino
    Testing needed. Added host rate limiting (default 10/s)
2026-03-02 Fix typo in comment for Request ID info
    [PoESP32-SNMP-Sensor.ino]
2026-03-02 Update I2C device addresses in PORTINFO.md
2026-03-02 Arduino-ESP v.3 compatibility
    Update Eth.begin to match new function parameters
    Change uint8->char hostname and SNMP read community
2026-03-02 Update for Arduino-ESP32 version 3 compatibility
    Clarified compatibility note regarding esp32 board library versions.
2026-04-07 Revise Arduino setup instructions for ESP32
    Updated installation steps for ESP32 board and libraries in Arduino setup.
2026-04-08 IDE 2.3.8, Arduino-ESP 3.3.7, new async SHT4X library
2026-04-08 Remove fixed size from AUTHORIZED_HOSTS array
    [PoESP32-SNMP-Environmental-Monitor.ino]
2026-04-08 Update warning about powered Ethernet port
2026-04-08 Revise requirements for M5Stack ESP32 Downloader kit
    Updated the requirements section to note the EOL status of the M5Stack ESP32 Downloader kit and provided a potential replacement link.
2026-04-08 Revise README with updated device requirements and instructions
    Updated requirements and programming instructions for M5Stack devices, including new product links and notes on compatibility.
2026-04-08 Update README with ESP32P4 configuration details
    Added instructions for setting ESP32P4 board parameters.
2026-04-08 Clarify M5Stack ESP32 Downloader kit requirement
2026-04-08 Update EOL replacement link for M5Stack ENV IV sensor
2026-04-09 Update Arduino setup instructions for clarity
2026-04-09 Update Arduino setup instructions for board manager
2026-04-09 Update ARDUINO-SETUP.md with important notes
    Clarified note about Arduino IDE and esp32 board library updates.
2026-04-09 Clarify CH9102 driver installation for PoESP32
2026-04-09 Remove note about MacOS 14.5 driver issue
    Removed note about CH9102 drivers not working on MacOS 14.5.
2026-04-12 Update replacement sensor description in README
    Clarified the requirements for the replacement sensor accessory in the README.
2026-07-25 Clarify upload process in Arduino instructions
    Added guidance on handling upload errors in Arduino.
2026-07-25 Change ESP32 installation version to 3.3.X
    Updated installation instructions for ESP32 board version.
2026-07-25 Replace ENV IV sensor with ENV III sensor details
    Updated sensor unit information and corrected model references.
2026-07-27 Update CH9102 driver installation instructions
    Clarified installation instructions for CH9102 USB-to-serial drivers.
2026-07-27 Clarify Windows driver installation instructions
2026-07-31 Add README for SHT4X temperature and humidity sensor
2026-07-31 3D Case Model
    [Bottom Shell - LCSC Connector.step, Top Shell - LCSC Connector.step]
2026-07-31 Add image to SHT4X README
    Added an image of the SHT4X sensor module to the README.
2026-07-31 Fix formatting in Readme.md assembly instructions
2026-07-31 Enhance Readme with assembly instructions and images
    Added detailed assembly instructions for JLCPCB and included images of the SHT4X board view and assembly.
2026-07-31 Fix formatting for BOM file verification in Readme
    Updated the Readme.md to correct formatting for BOM file verification instructions.
2026-07-31 Revise sensor information in README
    Updated sensor section in README to include custom SHT41-based sensor and its details.
2026-07-31 Fix wording for Unit-PoE-P4 device description
2026-07-31 Change nozzle size for 3D-printable case instructions
    Updated nozzle size recommendation for 3D printing.
2026-07-31 Clarify PCB production details in Readme
2026-07-31 Adjust sensor pricing in README
    Updated pricing information for SHT41-based sensor.
2026-08-27 Adjust humidity threshold for low heat mode
2026-09-07 Update sensor description in README.md
2026-09-07 Clarify sensor model options in README
2026-10-09 Update 3D-printing instructions in Readme
    Added additional printing specifications for the case.
